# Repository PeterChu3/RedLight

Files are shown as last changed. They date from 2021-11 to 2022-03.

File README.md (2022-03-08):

# RedLight

## Story

Mini Bike View

I ride around Atlanta on the electric mini bike pictured above. However, there is no lighting in the rear. Which according to car drivers can be hard to see at night. Rather than buy a cheap small internal battery powered red light from Amazon. I decided to make a overpowered blinking red light powered by the bike's battery to make sure everyone knows I exist on the road. I don't want to be hit by another car.

## Explanation

Uses a 555 timer and a n-channel mosfet to turn on/off LEDs.

The 555 timer is set to a 1-1.5 Hz signal astable square wave providing a steady rear LED.

The input voltage is 12v

rev# marks an existing PCB that has been ordered and purchased. After a rev# is submitted and purchased that revision will not be edited anymore and the next revision will be started. The current revision is rev1

#### Important links for design

LEDs
https://www.mouser.com/ProductDetail/941-XPEBRDL1R250601

LED datasheet
https://www.mouser.com/datasheet/2/723/XLampXPE2-2327163.pdf

LED Eye Safety
https://cree-led.com/media/documents/XLamp_EyeSafety.pdf

LED PCB Thermals
https://cree-led.com/media/documents/XLamp_PCB_Thermal.pdf

## Schematic and Board layout

Schematic view
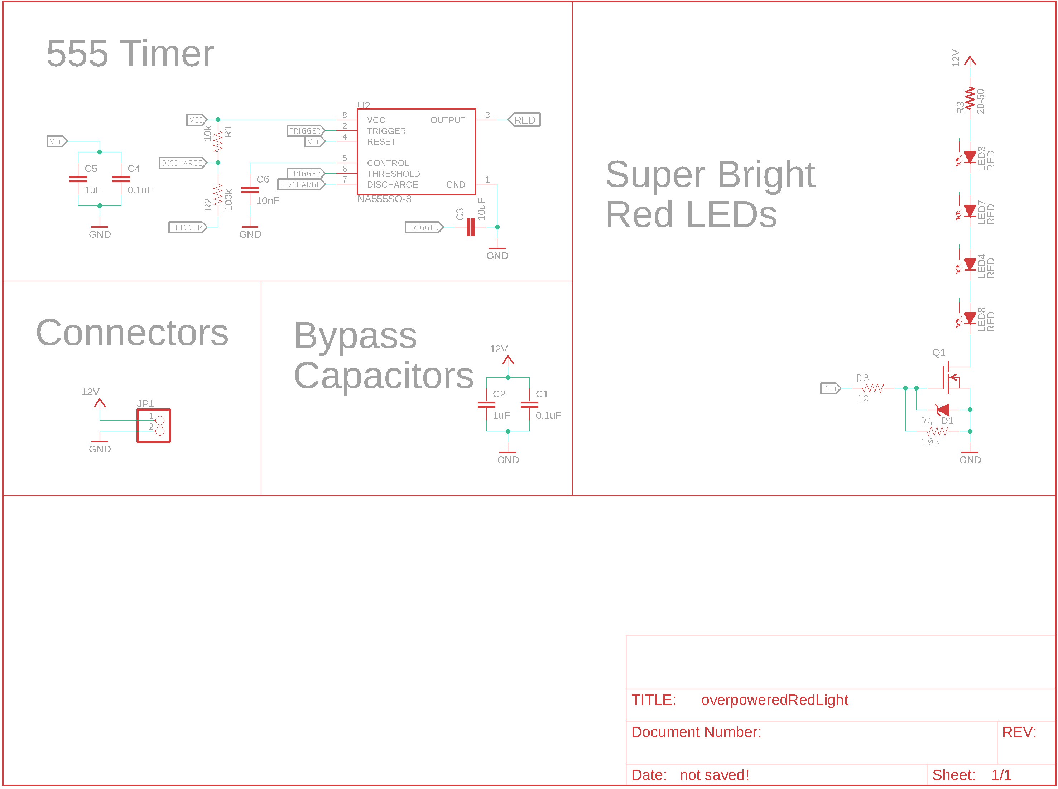
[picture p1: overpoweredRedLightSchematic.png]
Schematic View rev1


Layout view
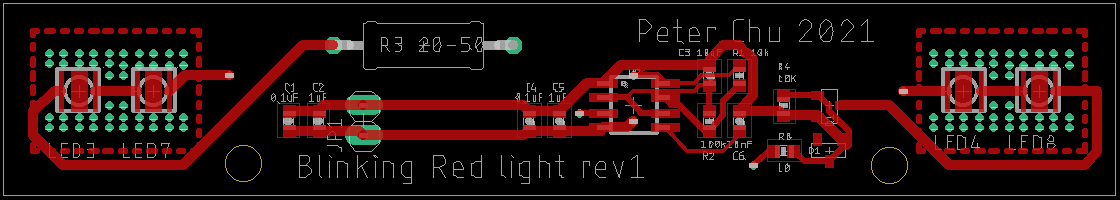
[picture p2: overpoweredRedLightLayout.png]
Layout View rev1


Board view
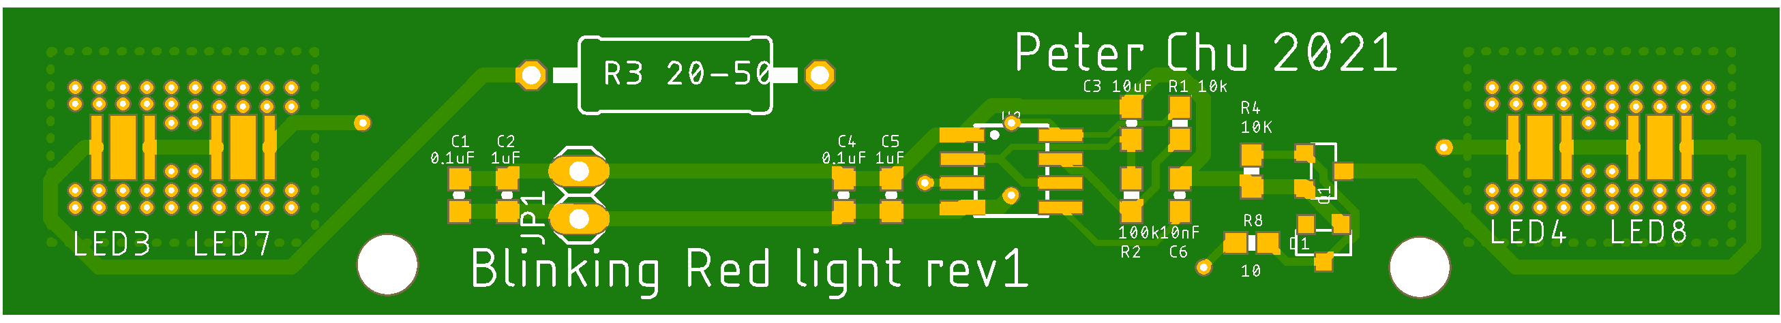
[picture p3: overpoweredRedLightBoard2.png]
Board View rev1


Functional test

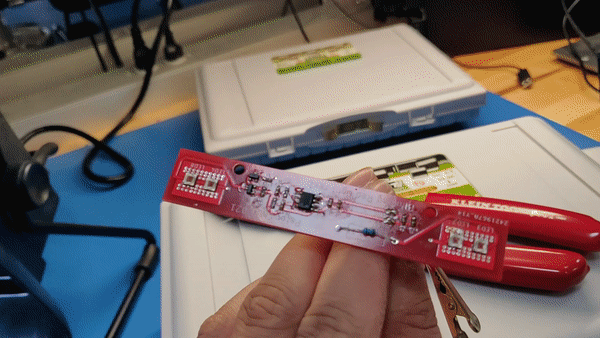
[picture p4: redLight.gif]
Red Light view


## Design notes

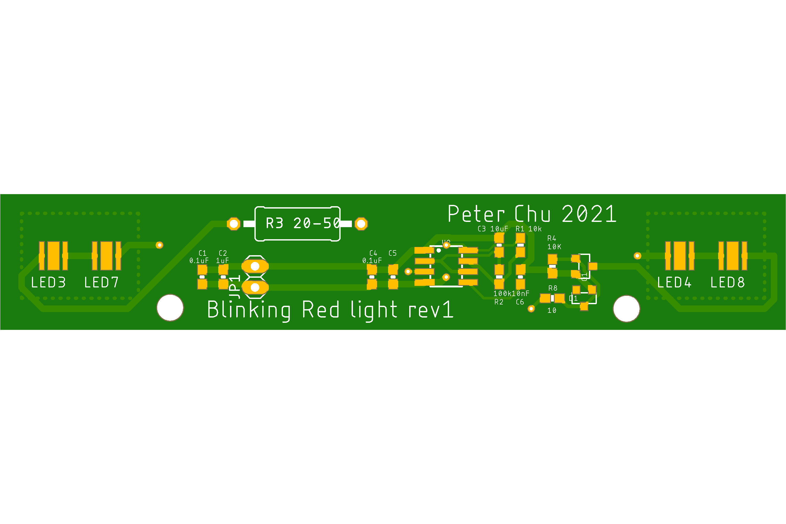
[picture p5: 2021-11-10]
overpoweredRedLight.png

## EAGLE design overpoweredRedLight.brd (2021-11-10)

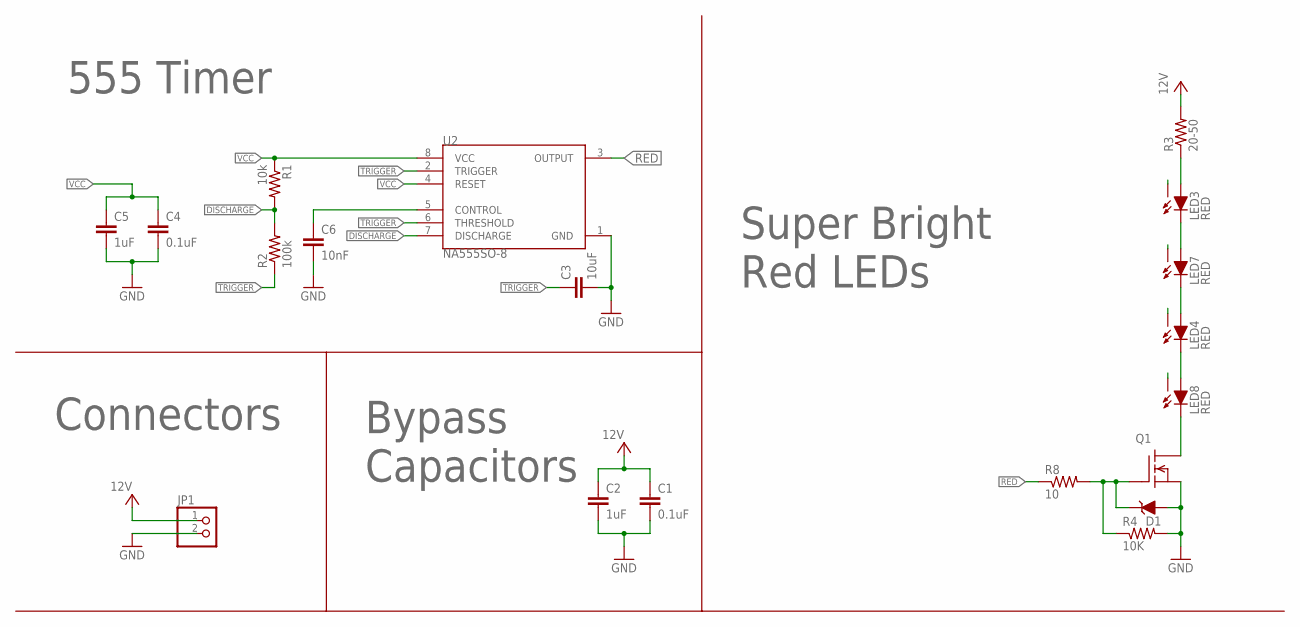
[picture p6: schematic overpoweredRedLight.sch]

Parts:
C1, C4: 0.1uF; 0603-CAP; TOLERANCE 5%; VOLTAGE 25V
C2, C5: 1uF; 0603-CAP; TOLERANCE 5%; VOLTAGE 25V
C3: 10uF; 0603-CAP; TOLERANCE 5%; VOLTAGE 25V
C6: 10nF; 0603-CAP; TOLERANCE 5%; VOLTAGE 25V
D1: MMBZ5246BLT1G; SOT23
JP1: PINHD-1X2; 1X02
LED3, LED4, LED7, LED8: RED; XP-E2
Q1: DMG3406LSOT; SOT23
R1: 10k; 0603-RES; TOLERANCE 1%
R2: 100k; 0603-RES; TOLERANCE 1%
R3: 20-50; 1W-0.6
R4: 10K; 0603-RES; TOLERANCE 1%
R8: 10; 0603-RES; TOLERANCE 1%
U2: NA555SO-8; SOIC-08

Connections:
DISCHARGE: R1.2, R2.2, U2.7 (DISCHARGE)
GND: C1.2, C2.2, C3.2, C4.2, C5.2, C6.2, D1.1 (A), JP1.2, Q1.2 (S), R4.2, U2.1 (GND)
unnamed: D1.3 (C), Q1.1 (G), R4.1, R8.2
unnamed: LED8.C, Q1.3 (D)
unnamed: LED3.A, R3.1
unnamed: C6.1, U2.5 (CONTROL)
unnamed: LED3.C, LED7.A
unnamed: LED4.A, LED7.C
unnamed: LED4.C, LED8.A
RED: R8.1, U2.3 (OUTPUT)
THERM1: LED4.X, LED8.X
THERM2: LED3.X, LED7.X
TRIGGER: C3.1, R2.1, U2.2 (TRIGGER), U2.6 (THRESHOLD)
VCC: C1.1, C2.1, C4.1, C5.1, JP1.1, R1.1, R3.2, U2.4 (RESET), U2.8 (VCC)

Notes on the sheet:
555 Timer
Super Bright Red LEDs
Connectors
Bypass Capacitors

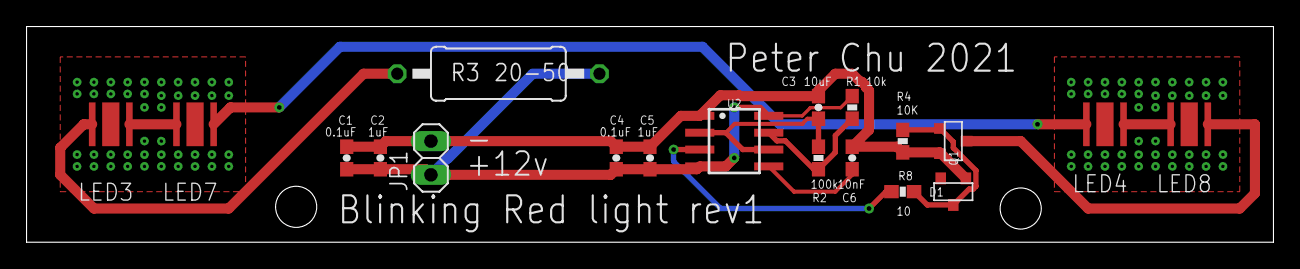
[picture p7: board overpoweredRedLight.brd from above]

Board: 2 copper layers, 94.0 x 16.3 mm, 19 parts (0 on the bottom side), 14 nets.

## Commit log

2021-11-10 Blinking Red light revision 1
    [DRILEGEND.CFG, overpoweredRedLight.brd, overpoweredRedLight.sch]
2021-11-10 Updated board image
2021-11-10 Edit silkscreen
    [overpoweredRedLight.brd]
2021-11-10 Final gerber files before submition to JLC
2022-03-08 Added functional circuit gif.
